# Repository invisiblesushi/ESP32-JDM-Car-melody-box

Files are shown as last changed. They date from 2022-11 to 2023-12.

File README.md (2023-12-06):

# 🎵 ESP32-JDM-Car-melody-box 🚗🎶

Car melody box that plays a startup sound/melody when power is supplied. It's meant to be mounted in a car.

## Button Mapping
- Single press  - Next or Previous mp3
- Long press    - Increase / Decrease volume
- Double click  - Set the current mp3 as default
- Switch        - Shuffle mode on/off

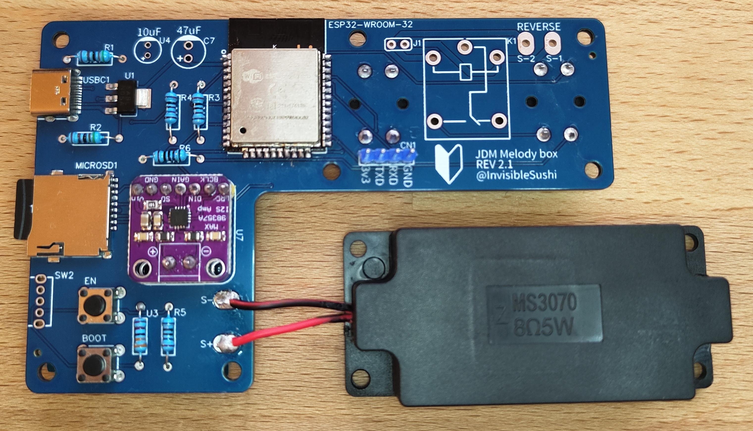
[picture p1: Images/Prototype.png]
Prototype Image


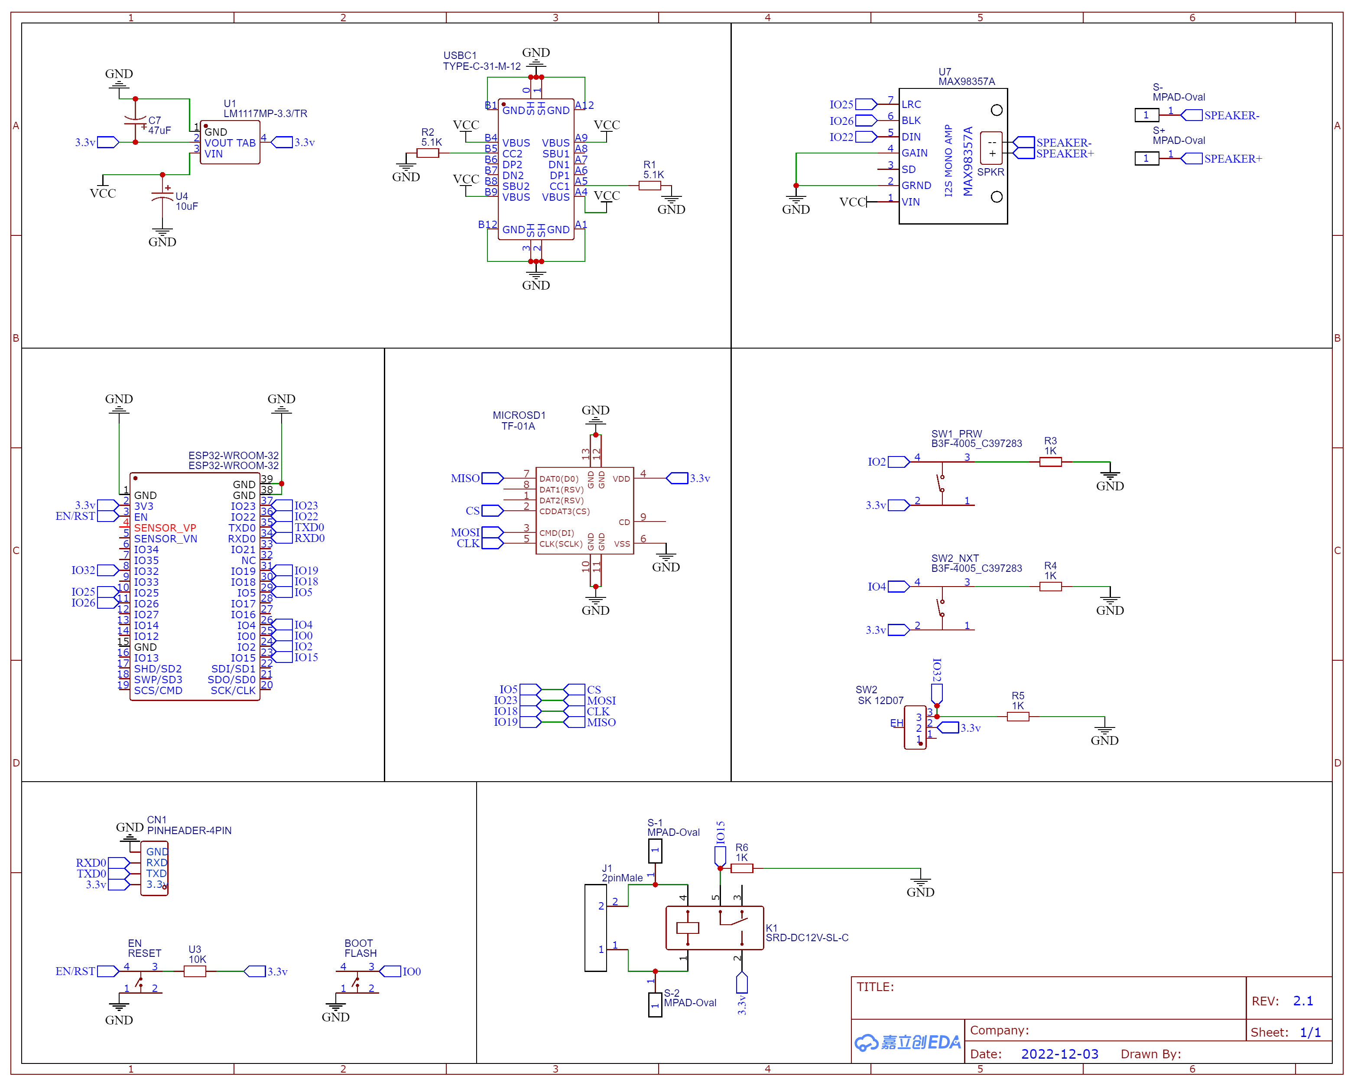
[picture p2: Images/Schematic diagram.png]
Schematic Diagram


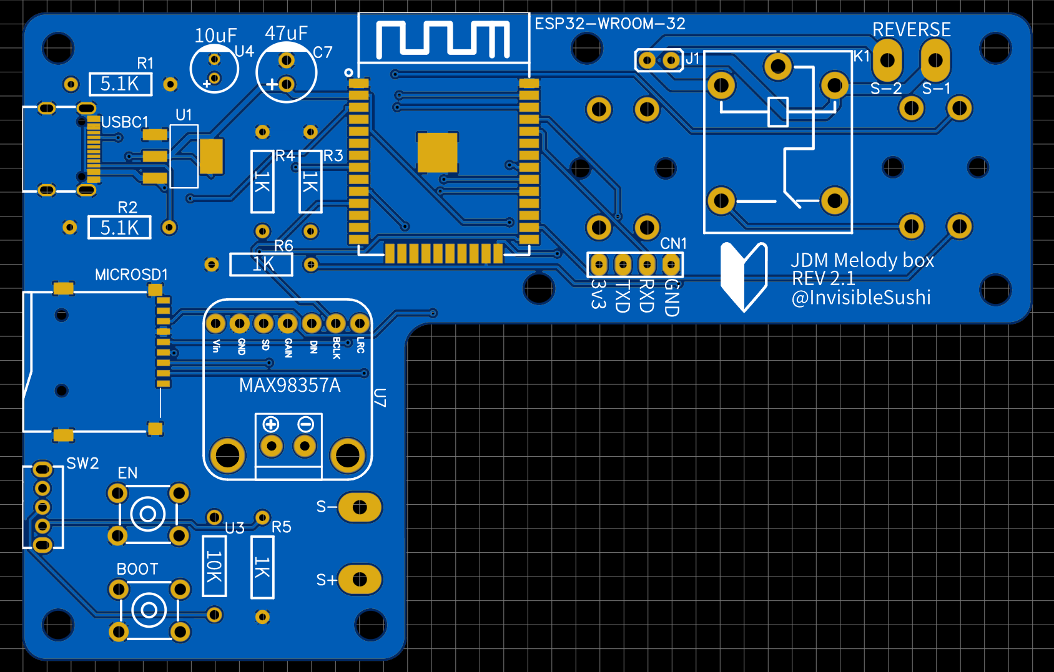
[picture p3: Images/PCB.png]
PCB Image


## Part List
- ESP32 wroom 32-u USB-C
- Max98357 I2S 3W Class D Amplifier
- Micro SD Storage Expansion Board
- Speaker
- SD card
- MP3 sound files

## Libraries
- [ESP32-audioI2S](https://github.com/schreibfaul1/ESP32-audioI2S)
- [OneButton](https://github.com/mathertel/OneButton)

## Sound File Source Examples:
- [Example 1](https://ko-fi.com/s/0c76c753a3)
- [Example 2](https://ko-fi.com/s/8723a46daa)

## SD Card Directory Structure:
- /startup_melody (Mp3 to be played at startup random)

## IDE
- 
- 



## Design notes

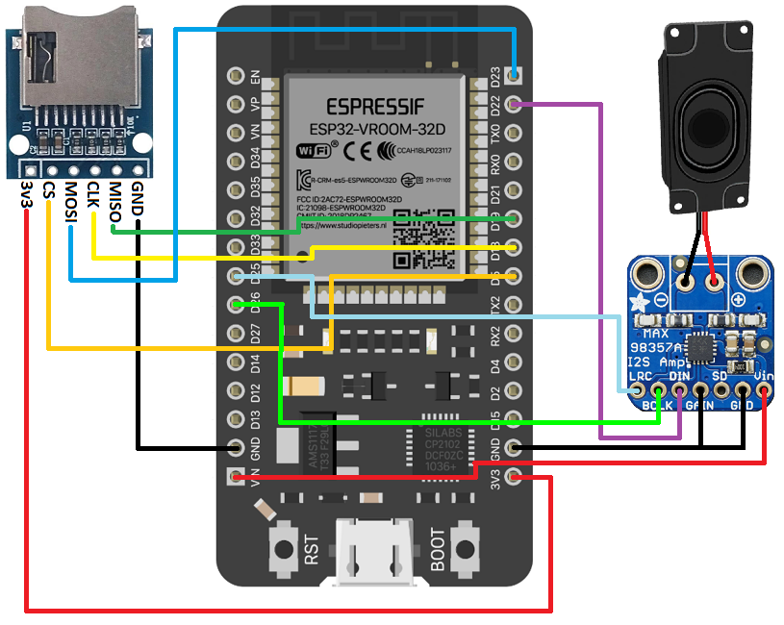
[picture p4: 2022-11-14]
Images/Schematic.png

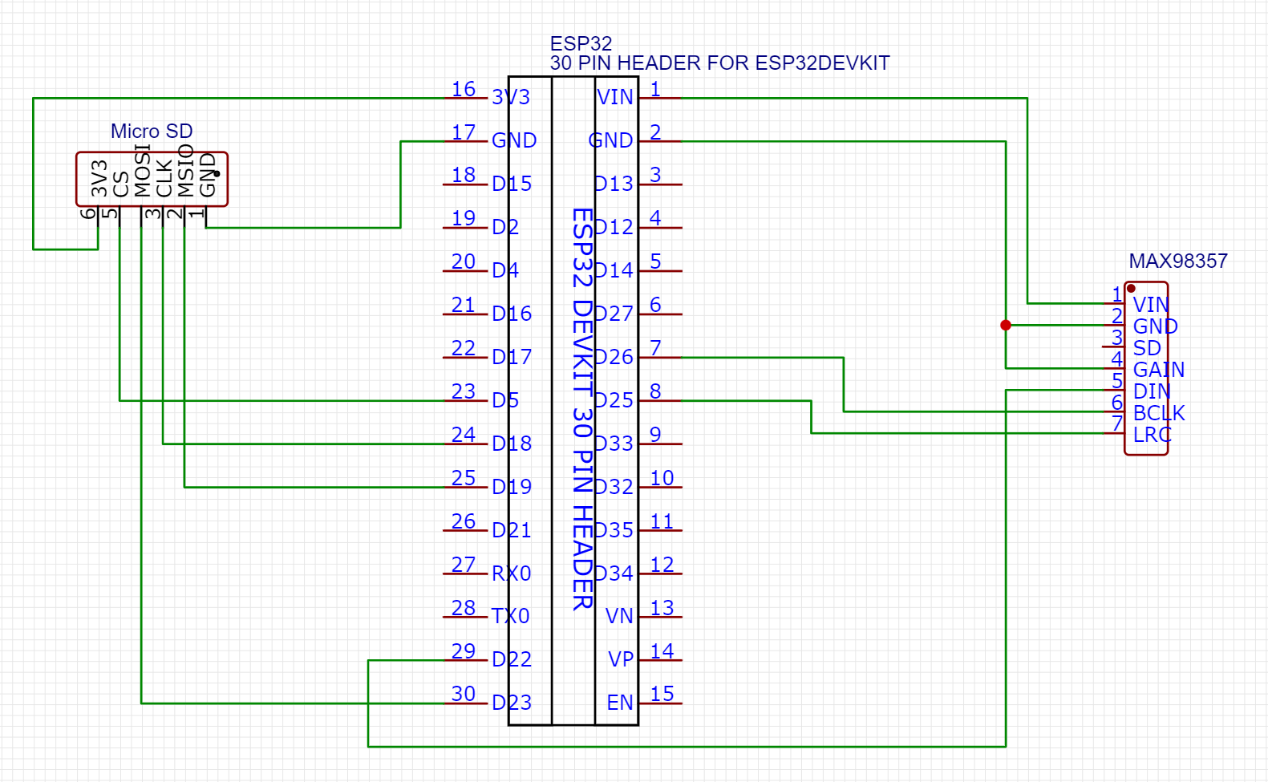
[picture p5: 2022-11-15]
Images/REV 1.0/Schematic diagram.png

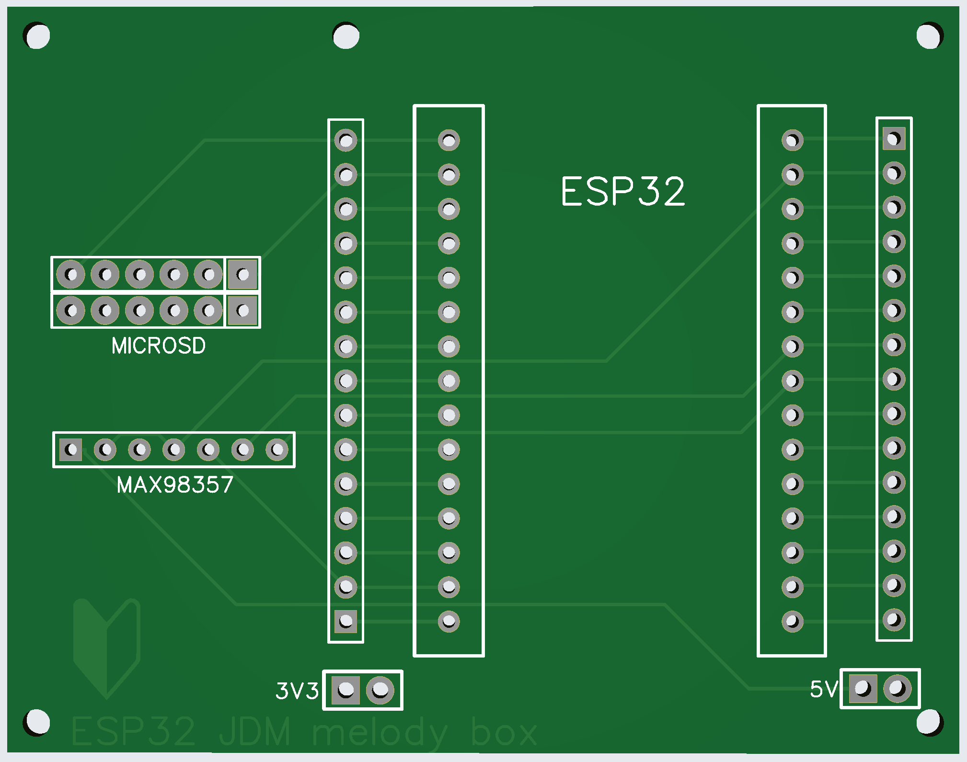
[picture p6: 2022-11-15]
Images/REV 1.0/PCB.png

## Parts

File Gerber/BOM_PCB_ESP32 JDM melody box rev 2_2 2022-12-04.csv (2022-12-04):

ID | Name | Designator | Footprint | Quantity | Manufacturer Part | Manufacturer | Supplier | Supplier Part | Price
1 | B3F-4005_C397283 | SW1_PRW,SW2_NXT | SW-TH_4P-L12.0-W12.0-P5.00-LS12.5-EH | 2 | B3F-4005 | OMRON(欧姆龙) | LCSC | C397283 | 0.141
2 | MPAD-Oval | S-1,S-2,S+,S- | PAD_OVAL | 4
3 | 2pinMale | J1 | 2PINMALE | 1
4 | 1K | R6,R3,R4,R5 | RES-TH_BD2.3-L6.5-P10.50-D0.5 | 4 | - | Chian Chia Elec | LCSC | C129910 | 0.016
5 | PINHEADER-4PIN | CN1 | PINHEADER-4PIN | 1
6 | SK 12D07 | SW2 | SW-TH_SK-12D07-X-X | 1 | SK-12D07-L2-B | XKB Enterprise | LCSC | C480338 | 0.103
7 | 47uF | C7 | CAP-TH_BD6.3-P2.50-D1.0-FD | 1 | 50YXF47MEFC6.3X11 | rubycon(红宝石) | LCSC | C107641 | 0.059
8 | 10uF | U4 | CAP-TH_BD5.0-P2.00-D0.5-FD | 1 | 50YXF10MHFC(5X11) | rubycon(红宝石) | LCSC | C3035375 | 0.053
9 | 5.1K | R1,R2 | RES-TH_BD2.3-L6.5-P10.50-D0.5 | 2 | - | Chian Chia Elec | LCSC | C129910 | 0.016
10 | LM1117MP-3.3/TR | U1 | SOT-223-3_L6.5-W3.4-P2.30-LS7.0-BR | 1 | LM1117MP-3.3/TR | HGSEMI | LCSC | C498153 | 0.135
11 | 10K | U3 | RES-TH_BD2.4-L6.3-P10.30-D0.6 | 1 | CFR-25JR-52-10K | YAGEO(国巨) | LCSC | C2649454 | 0.01
12 | FLASH | BOOT | KEY-TH_4P-L6.0-W6.0-P4.50-LS7.5 | 1 | TL1105F250Q | E-Switch | LCSC | C273474 | 0.472
13 | RESET | EN | KEY-TH_4P-L6.0-W6.0-P4.50-LS7.5 | 1 | TL1105F250Q | E-Switch | LCSC | C273474 | 0.472
14 | MAX98357A | U7 | MAX98357A | 1
15 | SRD-DC12V-SL-C | K1 | RELAY-TH_SRD-DCXXV-SL-C | 1 | SRD-DC12V-SL-C | Ningbo Songle Relay | LCSC | C688866 | 0.426
16 | ESP32-WROOM-32 | ESP32-WROOM-32 | WIFIM-SMD_ESP32-WROOM-32-N4 | 1 | ESP32-WROOM-32-N4 | ESPRESSIF(乐鑫) | LCSC | C82899 | 3.085
17 | TF-01A | MICROSD1 | TF-SMD_TF-01A | 1 | TF-01A | HRO | LCSC | C91145 | 0.18
18 | TYPE-C-31-M-12 | USBC1 | USB-C_SMD-TYPE-C-31-M-12 | 1 | TYPE-C-31-M-12 | 韩国韩荣 | LCSC | C165948 | 0.234

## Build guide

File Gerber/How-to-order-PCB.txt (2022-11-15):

How to Order PCB

Please refer to:
https://docs.easyeda.com/en/PCB/Order-PCB

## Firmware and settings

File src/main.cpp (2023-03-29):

#include <Arduino.h>
#include <Audio.h>
#include <SD.h>
#include <FS.h>
#include <OneButton.h>
#include <ArduinoJson.h>

// SD card connections
#define SD_CS 5
#define SD_MOSI 23
#define SD_MISO 19
#define SD_CLK 18

// Max98357 I2S connections
#define I2S_DOUT 22
#define I2S_BCLK 26
#define I2S_LRC 25

// Buttons
OneButton buttonPrevious = OneButton(
  2,            // Input pin for the button
  false,        // Button is active LOW
  false         // Enable internal pull-up resistor
);

OneButton buttonNext = OneButton(
  4,            // Input pin for the button
  false,        // Button is active LOW
  false         // Enable internal pull-up resistor
);

TaskHandle_t ButtonTask;

// Audio object
Audio audio;
int audio_volume = 10;

// File
File dir;
String startupMelodyDirectory = "/startup_melody";
String defaultMp3;
String currentMp3;
int fileCount = 0;
int fileIndex = 0;
String fileList[256];
int mp3Index = 0;
File jsonFile;
DynamicJsonDocument doc(1024);

int get_mp3_list(fs::FS fs, String dir_name, String fileList[256]){

  File dir = fs.open(dir_name);
  File file = dir.openNextFile();

  int i = 0;

  // Loops through all files in directory and add mp3 files to list
  while (file)
  {
    if (!file.isDirectory()){
      String temp_file = file.name();

      if (temp_file.endsWith(".mp3"))
      {
        fileList[i] = temp_file;
        i++;
      }
    }

    file = dir.openNextFile();
  }

  return i;
}

// Stop current playing mp3
void stop_mp3(){
  Serial.println("Stopping current mp3 playback");
  audio.stopSong();
  delay(200);           // Wait for to finish
}

// Next mp3
void next_mp3(){
  stop_mp3();

  int index = mp3Index;
  Serial.print("File index:");
  Serial.println(mp3Index);

  if (mp3Index < fileCount)
  {
    mp3Index++;
  }
  if (mp3Index >= fileCount)
  {
    mp3Index = 0;
  }
  
  String mp3_path = startupMelodyDirectory + "/" + fileList[mp3Index];
  Serial.println(mp3_path);

  // Play mp3
  audio.connecttoFS(SD, mp3_path.c_str());
}

// Previous mp3
void previous_mp3(){
  stop_mp3();

  int index = mp3Index;
  Serial.print("File index:");
  Serial.println(mp3Index);

  if (mp3Index <= fileCount)
  {
    mp3Index--;
  }
  if (mp3Index <= 0)
  {
    mp3Index = fileCount - 1;
  }
  
  String mp3_path = startupMelodyDirectory + "/" + fileList[mp3Index];
  Serial.println(mp3_path);

  // Play mp3
  audio.connecttoFS(SD, mp3_path.c_str());
}

void readConfigFile(){
  Serial.println("Config file:");
  jsonFile = SD.open("/config.json", FILE_READ);

  if (!jsonFile) {
    Serial.println("Failed to open JSON file, reverting to default values");
  }

  // Parse JSON file
  DeserializationError error = deserializeJson(doc, jsonFile);
  if (error) {
    Serial.println("Error on parsing JSON file.");
  }

  // Extract values from JSON
  audio_volume = doc["audio_volume"].as<int>();
  audio.setVolume(audio_volume);

  defaultMp3 = doc["default_mp3"].as<String>();

  Serial.println(audio_volume);
  Serial.println(defaultMp3);

  jsonFile.close();  
}

void updateConfigFile(){
  // Open JSON file for writing
  jsonFile = SD.open("/config.json", FILE_WRITE);
  if (!jsonFile) {
    Serial.println("Failed to open JSON file for writing.");
    while (1);
  }

  // Update JSON object with new values
  doc["audio_volume"] = audio_volume;
  doc["default_mp3"] = defaultMp3;

  // Serialize JSON object and write to file
  if (serializeJson(doc, jsonFile) == 0) {
    Serial.println("Failed to write updated JSON to file.");
  }
  else{
    Serial.println("Config file updated");
  }

  // Close JSON file
  jsonFile.close();
}


// Volume control - increase
void increase_volume(){
  if (audio_volume <= 21)
  {
    audio_volume++;
  }
  audio.setVolume(audio_volume);
  Serial.print("Volume:");
  Serial.println(audio_volume);
  updateConfigFile();
  delay(200);
}

// Volume control - decrease
void decrease_volume(){
  if (audio_volume > 1)
  {
    audio_volume--;
  }
  audio.setVolume(audio_volume);
  Serial.print("Volume:");
  Serial.println(audio_volume);
  updateConfigFile();
  delay(200);
}


void init(){
  // Initialize serial port
  Serial.begin(115200);

  // Initialize SD card
  pinMode(SD_CS, OUTPUT);      
  digitalWrite(SD_CS, HIGH); 
  SPI.begin(SD_CLK, SD_MISO, SD_MOSI);

  if(!SD.begin(SD_CS))
  {
    Serial.println("Error accessing microSD card");
    while(true); 
  }

  dir = SD.open(startupMelodyDirectory);

  // Setup I2S 
  audio.setPinout(I2S_BCLK, I2S_LRC, I2S_DOUT);
    
  // Set Volume
  audio.setVolume(audio_volume);      //21 max volume
}

void setCurrentMp3(){
  Serial.println("setCurrentMp3");
  defaultMp3 = currentMp3;
  updateConfigFile();
}

//Buttom task
void Task_buttonHandler( void * pvParameters ){
  Serial.print("Task_buttonHandler running on core ");
  Serial.println(xPortGetCoreID());

  for(;;){
    // keep watching the push buttons:
    buttonPrevious.tick();
    buttonNext.tick();
  }
}

void init_btn(){
  // link the button 1 functions.
  buttonPrevious.attachClick(previous_mp3);
  buttonPrevious.attachDuringLongPress(decrease_volume);
  buttonPrevious.attachDoubleClick(setCurrentMp3);

  // link the button 2 functions.
  buttonNext.attachClick(next_mp3);
  buttonNext.attachDuringLongPress(increase_volume);
  buttonNext.attachDoubleClick(setCurrentMp3);


  //create a task that will be executed in the Task1code() function, with priority 1 and executed on core 0
  xTaskCreatePinnedToCore(
                    Task_buttonHandler,           /* Task function. */
                    "Task_buttonHandler",         /* name of task. */
                    10000,                        /* Stack size of task */
                    NULL,                         /* parameter of the task */
                    tskIDLE_PRIORITY,             /* priority of the task */
                    &ButtonTask,                       /* Task handle to keep track of created task */
                    0);                           /* pin task to core 0 */     
}

String randomMp3(int fileNumber){
    mp3Index = random(fileNumber);
    Serial.print("Mp3 index: ");
    Serial.println(mp3Index);
    return fileList[mp3Index];  
}

bool checkExist(String fileName){
  if (SD.exists(startupMelodyDirectory + "/" + fileName))
  {
    Serial.println("File found");
    return true;
  }
  else{
    Serial.println("File not found");
    return false;
  }
  
}

void setup() {
  init();
  init_btn();
  readConfigFile();

  // Adds all mp3 files in directory to fileList
  fileCount = get_mp3_list(SD, startupMelodyDirectory, fileList);
  Serial.print("Mp3 list count: ");
  Serial.println(fileCount);

  String mp3_path;  

  pinMode(32, INPUT_PULLUP);
  bool shuffleSwitch = digitalRead(32);

  if(shuffleSwitch == HIGH && checkExist(defaultMp3) == true){
    Serial.println("Shuffle OFF");
    currentMp3 = defaultMp3;
    mp3_path = startupMelodyDirectory + "/" + currentMp3;
  }
  else{
    Serial.println("Shuffle ON");
    currentMp3 = randomMp3(fileCount);
    mp3_path = startupMelodyDirectory + "/" + currentMp3;
  }

  // Play mp3
  Serial.print(mp3_path);
  audio.connecttoFS(SD, mp3_path.c_str());
}

void loop() {
  audio.loop();
}

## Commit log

2022-11-15 Create Schematic diagram.png
2022-11-15 Added Gerber files
    Made in EasyEDA
    [Drill_NPTH_Through.DRL, Drill_PTH_Through.DRL, Drill_PTH_Through_Via.DRL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]
2022-12-04 PCB rev 2.1
    [BOM_PCB_ESP32 JDM melody box rev 2_2 2022-12-04.csv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]
2022-12-04 PCB Schematic
2022-12-04 PCB Schematics
